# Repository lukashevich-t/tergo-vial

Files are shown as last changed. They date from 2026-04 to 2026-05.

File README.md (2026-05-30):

### Фичи:

- Раскладка Jiran (ну, почти...)
- Backlight
- Двойной shift работает как Enter
- Отображение состояния Caps/Num lock на экране
- отображение на экране текущего слоя клавы
- Отображение на экране активного на компе языка ввода (нужен агент на компе)
- Отображение активного на компе языка ввода в виде горящей/погасшей подсветки (нужен агент на компе)
- Активация режима Bootloader:
  - Если сбросить при нажатой кнопке 3 (только для левой половины)
  - Если на 3-м слое нажать 3 (на левой половине) или 8 (на правой)
  - Если сбросить при нажатой кнопке Boot на макетке (стандарт для RP2040)
  - "двойной клик" по сбросу
- На 3-м управляющем слое кнопка 5 (6) выдаёт на экран логотип и выплёвывает кой-какую информацию в debug console

### Структура папок

```
.
├── hardware                     # железная часть проекта
│   ├── case                     # Проекты корпусов
│   │   ├── tergo-choc           # Корпус для варианта tergo-choc
│   │   └── tergo-mx             # Корпус для варианта tergo-mx
│   ├── pcb                      # Проекты печатных плат
│   │   ├── 3rd-party-libs       # Сторонние библиотеки, откуда я взял символы и посадочные места для проектирования PCB
│   │   ├── common               #
│   │   │   └── libs             # Моя сборная библиотека символов и посадочных мест для KiCAD. Этот путь нужно прописать в Kicad в переменную TERGO_LIBS ("Preferences -> Configure paths")
│   │   ├── tergo-choc           # PCB для варианта tergo-choc
│   │   └── tergo-mx             # PCB для варианта tergo-mx
│   └── temp                     # Всякие временные тестовые файлы для прототипирования (KiCAD, FreeCAD...). Не для хранения в git
├── host-software                # ПО для ПК (взаимодействие ПК с клавиатурой)
│   ├── cinnamon-extension       # расширение для Cinnamon desktop для отображения текущей раскладки клавиатуры на экране клавиатуры
│   ├── cinnamon-extension-old   # предыдущая реализация (на javascript) расширения для Cinnamon desktop для отображения текущей раскладки клавиатуры на экране клавиатуры
│   └── windows-QmkLayoutMonitor # агент для Windows для отображения текущей раскладки клавиатуры на экране клавиатуры
├── layouts                      # Исходные коды прошивки для различных вариантов
│   ├── tergo-choc               # прошивка QMK-vial для варианта на low-profile свичах Kailh choc v1 (1350)
│   │   └── common.h             # Тут описаны отладочные макроопределения, которые могут печатать значения других макроопределений во время компиляции. Как использовать, см. ниже
│   └── tergo-mx                 # прошивка QMK-vial для варианта на свичах Cherry MX
│       └── common.h             # см. выше
└── logo                         # Битмап логотипа и шрифт, которым он напечатан. Скрипт для создания проявляющегося лого (см. инструкцию ниже)
    └── old_scripts              # старые скрипты для перегона битмапов в массив байтов для экрана. после отказа от драйвера OLED (перешел на Quantum painter) - потеряли актуальность.
/mnt/media/work/vial-qmk/keyboards/tergo/layouts/layout-tergo-mx/common.h
```

Пример использования отладочных макроопределений из файла `common.h`:

```c
#pragma message "RAW_USAGE_ID " DESCRIBE_MACRO_VALUE(RAW_USAGE_ID)
#pragma message DESCRIBE_MACRO(QMK_KEYBOARD_H)
```

### Preparation

- TBD...
- After cloning git repository, go to Kicad path variables and define variable `TERGO_LIBS` to point to <repo>/pcb/common/libs, i.e.: `TERGO_LIBS => /home/tim/work/qmk_firmware/keyboards/tergo/pcb/common/libs`

### Печать корпуса

- Примечание: иногда при экспорте файлов STL из проекта freecad они получаются битые - слайсер ругается на них. В этом случае попробовать отключить/включить активность импортируемого тела, поворочать, экспортировать снова... Короче, поплясать с бубном.
- Из проекта Freecad (`./case/case-left.FCStd`) экспортировать в формат STL тело "full-top-new" - это верх левой половины.
- Верх правой половины получить средствами слайсера (отзеркалить).
- Напечатать.
- Эспортировать тела "full-bottom-new-left-with-logo" и "full-bottom-new-left-with-logo".
- Напечатать.

### Отображение раскладки клавиатуры

- скомпилить поддержку HID RAW (`RAW_ENABLE = yes` и обработчик сообщений).
- прошить в клаву
- для Linux Mint cinnamon edition использовать проект `_cinnamon-extension` или `_cinnamon-extension-old`
- Для Windows собрать `_windows-QmkLayoutMonitor` в соответствии с инструкцией в папке

### Логотип

- Подготовить файл `logo/logo.png` с разрешением 320x1280 пикселей (вертикальная ориентация). Лучше всего будет смотреться белые буквы на черном фоне.
- В скрипте `logo/create-logo-animation.py` подобрать под себя количество и длительность кадров анимации.
- Если логотип скорее черный на белом, придётся подправить скрипт:
  - `if img_1bit.getpixel((x, y)) > 0:` заменить на `if img_1bit.getpixel((x, y)) == 0:`
  - `current_frame.putpixel(px, 255)` заменить на `current_frame.putpixel(px, 0)`
- запустить питонский скрипт:

```bash
cd logo
python3 create-logo-animation.py
```

- появится папка с отдельными кадрами, а также анимированный файл `logo.gif`
- натравить на него преобразователь картинок:

```bash
rm -rf converted-image && mkdir -p converted-image && qmk painter-convert-graphics -f mono2 -o ./converted-image -i logo.gif
```

- содержимое папки `logo/converted-image/logo.qgf.*` переписать в `split/display/` с заменой файлов.
- Пересобрать прошивку.

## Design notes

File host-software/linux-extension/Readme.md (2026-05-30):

## tergo-layout@tlukashevich.com
Расширения для Cinnamon desktop и Gnome desktop для отправки сообщений о смене раскладки в клавиатуру T-Ergo на основе прошивки QMK-vial  

### Установка
- при желании можно заново скомпилировать программу для общения с клавиатурой:
```bash
apt install libhidapi-dev gcc -y 
gcc send_hid.c -o send_hid -lhidapi-hidraw -s
```
- В файлах `cinnamon.yaml` и `gnome.yaml` в секции переменных указать "координаты" клавиатуры: vid (5954), pid(0003) и hid_raw_usage_page (FF60 по умолчанию для клавиатур на QMK)
- запустить установку для нужного десктопа:
```bash
ansible-playbook cinnamon.yaml -K
# или ansible-playbook gnome.yaml -K
```
- перезапустить рабочий стол (просто выйти и зайти не сработает):
```bash
systemctl restart display-manager # для gnome
systemctl restart lightdm # для cinnamon
```

### Полезные команды
#### Gnome
```bash
# отключить расширение:
gnome-extensions disable tergo-layout@tlukashevich.com
# Перезагрузить расширение. Всё равно не работает, и надо при изменениях перестартовать display-manager:
gnome-extensions reset tergo-layout@tlukashevich.com
# включить расширение
gnome-extensions enable tergo-layout@tlukashevich.com
# список включённых расширений
gsettings get org.gnome.shell enabled-extensions
# список всех расширений
gnome-extensions list
```

Наблюдать за логами:
```bash
journalctl -f -g 'tergo'
```

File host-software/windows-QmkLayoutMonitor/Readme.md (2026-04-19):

## QML Layout monitor
Агент для Windows, отслеживающий изменения раскладки и передающий эту информацию в T-Ergo keyboard
### Установка
- при желании можно заново скомпилировать.
  - Потребуется MS Visual Studio 2022 с включенной опцией "Windows C++ development"
  - Запустить Developer Command Prompt for Visual Studio 2022
  - перейти в папку с проектом и собрать:
```cmd
cd e:\temp\QMKLayoutMonitor\QMKLayoutMonitor
cl /EHsc *.cpp /Fe:QMKLayoutMonitor.exe /link /SUBSYSTEM:WINDOWS
# или с оптимизацией:
cl /EHsc /O1 /MD *.cpp /Fe:QMKLayoutMonitor.exe /link /SUBSYSTEM:WINDOWS
```
- для установки запустить так:
```cmd
QmkLayoutMonitor.exe <VID> <PID> <USAGE_PAGE> install
```
Программа скопирует себя в %APPDATA% (c:/Users/tim/AppData/Roaming/QMKLayoutMonitor/QMKLayoutMonitor.exe) и создаст ярлык в автозапуске (`shell:startup`) с указанными параметрами VID, PID и USAGE_PAGE.

### Прочие заметки
- Чтобы писать отладочные сообщения в файл `layout_monitor.log` в папке с программой, надо прописать в коде `#define DEBUG` и перекомпилировать.
- просто запустить:
```cmd
QmkLayoutMonitor.exe <VID> <PID> <USAGE_PAGE>
# Пример:
QmkLayoutMonitor.exe 0x5954 0x0003 0xFF60
```
- Проверить связи с клавиатурой:
```cmd
QmkLayoutMonitor.exe 0x5954 0x0003 0xff60 test
```
программа просто отправит в клавиатуру текущую раскладку и завершится.
- Программе не всегда приходят уведомления о смене раскладки. Например, при смене раскладки с EN на RU через иконку в system tray. При смене раскладки в обратную сторону через system tray - обновления приходят.
- С помощью ИИ перепробовал кучу вариантов:
  - Через Text Services Framework - но оказалось, что тут уведомления приходят только о смене раскладки для нашего приложения, а не для глобально
  - Через периодический опрос - это мне не нравится, хотя так сделано в клавиатуре stront ([вот](https://github.com/zzeneg/qmk-hid-host) проект на Rust)
  - Через перехват WM_SHELL - это по словам ИИ не работает начиная с Windows 8
  - Комбинированный метод, который у нас тут и используется: отслеживаем изменение активного окна плюс отпускание кнопок, которые применяются в переключении языков (Ctrl, Shift, Alt, Win...). Это работает почти хорошо.

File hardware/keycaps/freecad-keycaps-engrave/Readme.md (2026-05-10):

# Назначение
Макрос FreeCAD для нанесения гравировки на кейкапы [KLP-Lame](https://github.com/braindefender/KLP-Lame-Keycaps)  
Испытывался на кейкапах "Choc stem - choc size" в FreeCAD v1.1.1  

# Установка
проще всего создать симлинки:
```bash
cd $HOME/.local/share/FreeCAD/v1-1/Macro
ln -s /path_to_repo/freecad-keycaps-engrave/keycap_engrave.FCMacro
ln -s /path_to_repo/freecad-keycaps-engrave/keycap_engrave_libs
```

Но можно и просто скопировать файл `keycap_engrave.FCMacro` и папку `keycap_engrave_libs` в `$HOME/.local/share/FreeCAD/v1-1/Macro/`  

# Разработка
Для настройки удобств при разработке макросов для FreeCAD в VS Code + Pylance придётся сделать кучу шагов:
- Freecad поставляется в формате AppImage, а это по сути образ squashfs. Настроим, чтобы он всегда монтировался:
```bash
sudo mkdir /mnt/freecad
# Узнаем, с какого смещения в файле Appimage начинается собственно образ:
OFFSET=`/opt/AppImages/FreeCAD_1.1.1-Linux-x86_64-py311.AppImage --appimage-offset`
echo "/opt/AppImages/FreeCAD_1.1.1-Linux-x86_64-py311.AppImage /mnt/freecad   squashfs        loop,offset=$OFFSET      0 0" | sudo tee -a /etc/fstab
```

- установить freecad-stubs:
	a. из гитхаба:
	```bash
	mkdir -p /home/tim/work/freecad && cd $_
	git clone https://github.com/ostr00000/freecad-stubs.git
	```
	b. в виртуальное окружение
	```bash
	mkdir -p /home/tim/work/freecad && cd $_
	python3 -m venv freecad-venv
	source freecad-venv/bin/activate
	pip3 install freecad-stubs
	```
- в проекте создать файл `.vscode/settings.json`:
```json
{
	"files.associations": {
	    "*.FCMacro": "python" // чтобы VSCode считал файлы *.FCMacro кодом на Python
	},
    "python.analysis.extraPaths": [
      "./libs", // просто наша либа в рамках проекта
      "/mnt/freecad/usr/bin", // пути к папкам с so-файлами Freecad
      "/mnt/freecad/usr/lib"
    ],
	"python.analysis.stubPath": "/home/tim/work/freecad/freecad-stubs/freecad_stubs", // путь к стабам (биндингам)
	"python.analysis.typeCheckingMode": "standard",
}
```

# Проблемы
Иногда случаются проблемы при нанесении гравировки. Помогает открыть проблемный кейкап в FreeCAD и поднять выдавленный 3Д-текст на 1 мкм по оси Z.

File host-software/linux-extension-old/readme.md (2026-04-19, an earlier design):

## cinnamon-to-tergo
Расширение для Cinnamon desktop для отправки сообщений о смене раскладки в клавиатуру T-Ergo на основе прошивки QMK  
## Установка
- установка необходимых библиотек
```bash
sudo apt install libhidapi-hidraw0
```
- Установка nodejs
```bash
apt install nodejs
cd /path/to/git/repo/_cinnamon-extension/cinnamon-to-tergo@tlukashevich.com
npm install

# Скопировать проект в папку расширений cinnamon:
cp -r /path/to/git/repo/_cinnamon-extension/cinnamon-to-tergo@tlukashevich.com ~/.local/share/cinnamon/extensions/
# или сделать ссылку:
ln -s /path/to/git/repo/_cinnamon-extension/cinnamon-to-tergo@tlukashevich.com ~/.local/share/cinnamon/extensions/cinnamon-to-tergo@tlukashevich.com
```
- настройка udev - дать доступ к устройству обычному пользователю. Проверить правильность Vendor ID/Product ID:
```bash
echo -e 'SUBSYSTEM=="hidraw", ATTRS{idVendor}=="5954", ATTRS{idProduct}=="0003", MODE="0666"\nSUBSYSTEM=="usb", ATTRS{idVendor}=="5954", ATTRS{idProduct}=="0003", MODE="0666"' | sudo tee /etc/udev/rules.d/99-qmk-raw-hid.rules
sudo udevadm control --reload-rules
sudo udevadm trigger
```
- **Переподключить клавиатуру!!!**
- Запустить отладчик Looking glass из состава Cinnamon (запустить команду `lg` или назначить и нажать горячую кнопку)
- Активировать расширение: Запустить "Параметры -> Расширения". Там должно быть наше расширение. Выделить его и нажать плюс внизу окна
- При активации Cinnamon может упасть, но потом всё работает
- Перезапустить Cinnamon. Это можно сделать без выхода:
  - из Looking glass -> Actions
  - Нажать Alt+F2 (или Win+R) и запустить команду `r` (да, одна буква)
- Логи можно смотреть в том же Looking glass

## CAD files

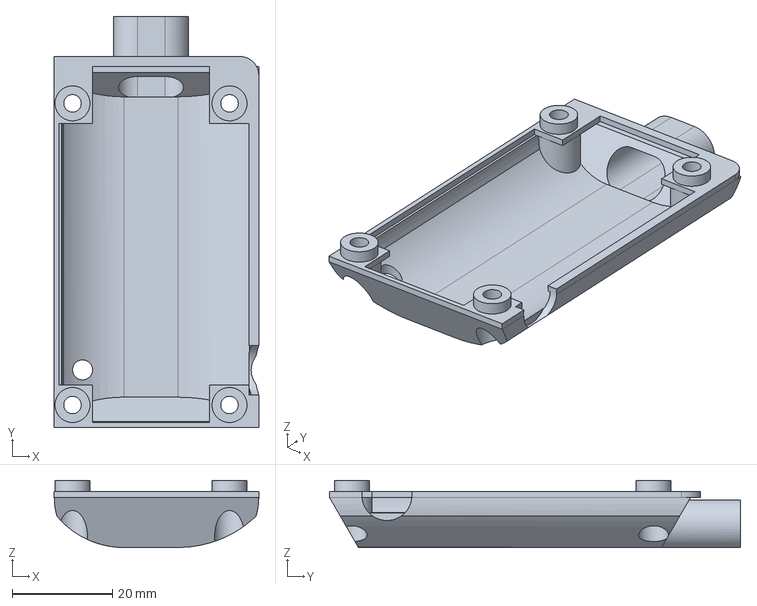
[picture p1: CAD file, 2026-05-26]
hardware/case/tergo_choc/case-choc.FCStd
40.9 x 82.2 x 13.4 mm

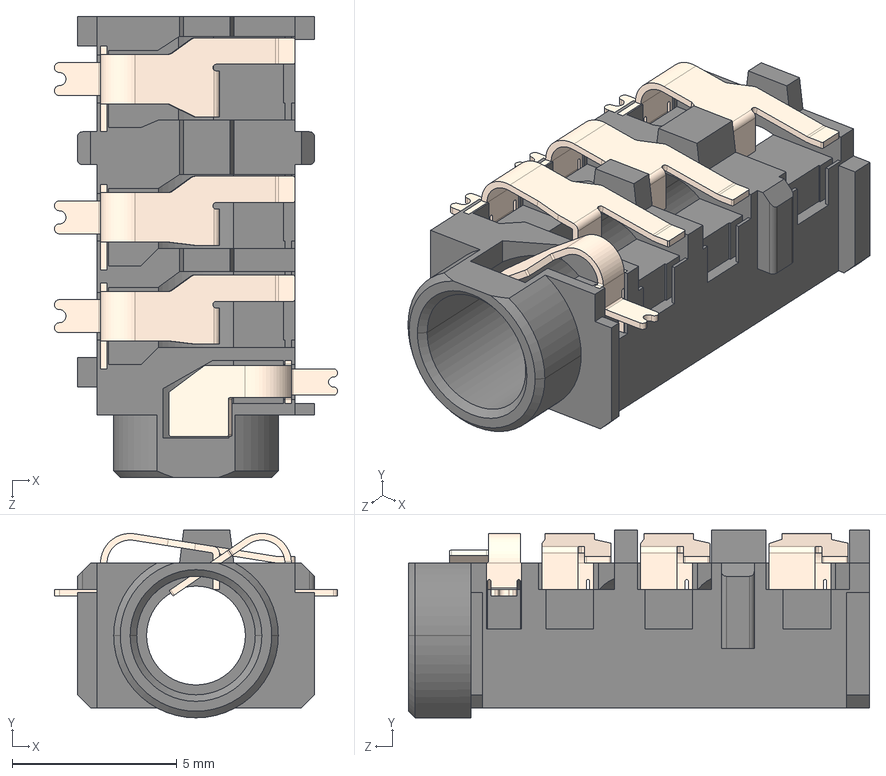
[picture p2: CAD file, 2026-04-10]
hardware/pcb/3rd-party-libs/keebio-parts/3dmodels/CUI_SJ-43614-SMT-TR.step
8.60 x 5.70 x 14.0 mm

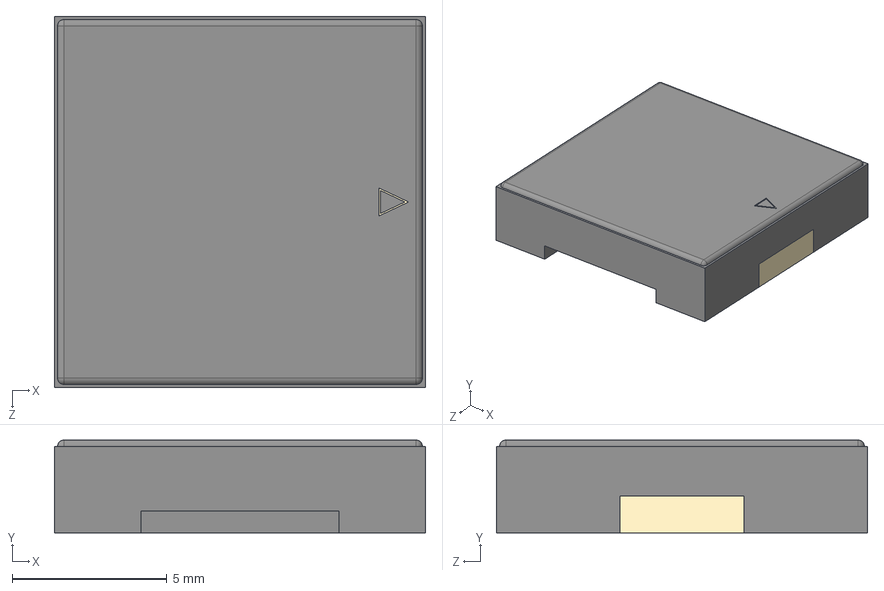
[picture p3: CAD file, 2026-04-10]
hardware/pcb/3rd-party-libs/speaker/PKLCS1212E4001-R1.step
12.0 x 3.00 x 12.0 mm

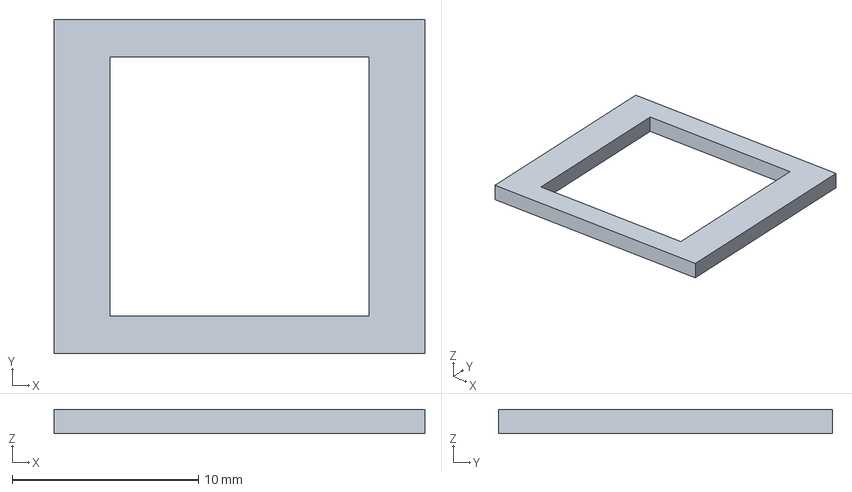
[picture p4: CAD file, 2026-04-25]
hardware/temp/choc-plate.FCStd
19.9 x 17.9 x 1.30 mm

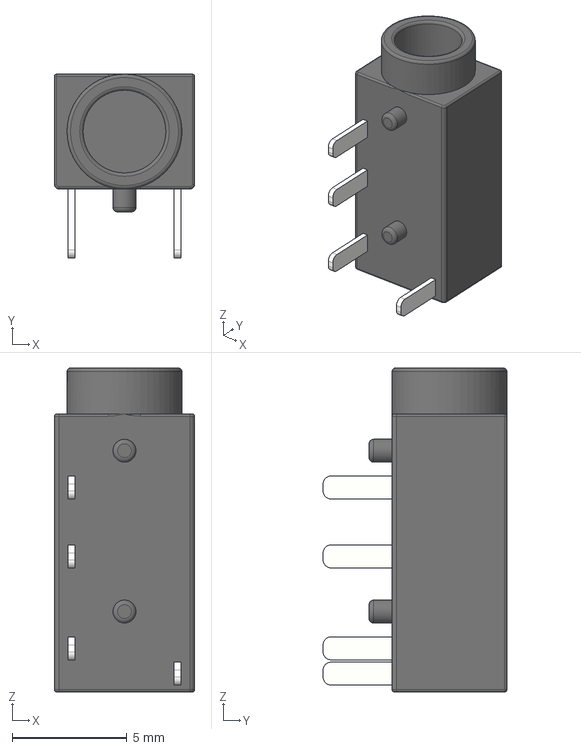
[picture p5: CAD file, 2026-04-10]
hardware/pcb/3rd-party-libs/keebio-parts/3dmodels/PJ-320A.step
6.10 x 8.00 x 14.1 mm

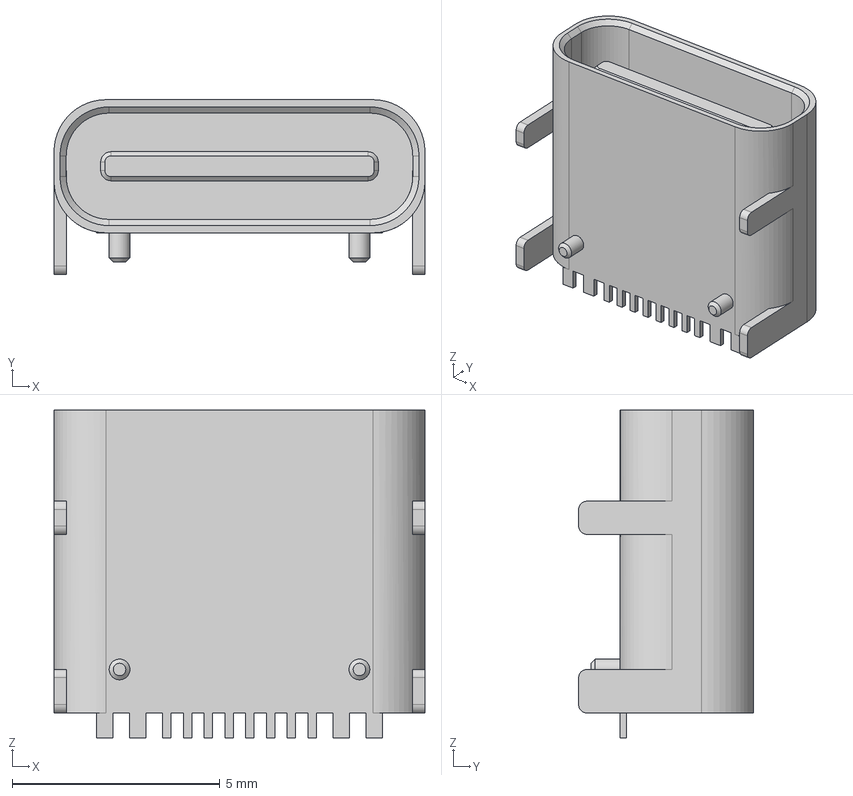
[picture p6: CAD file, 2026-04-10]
hardware/pcb/3rd-party-libs/keebio-parts/3dmodels/HRO TYPE-C-31-M-12.step
8.94 x 4.21 x 7.90 mm

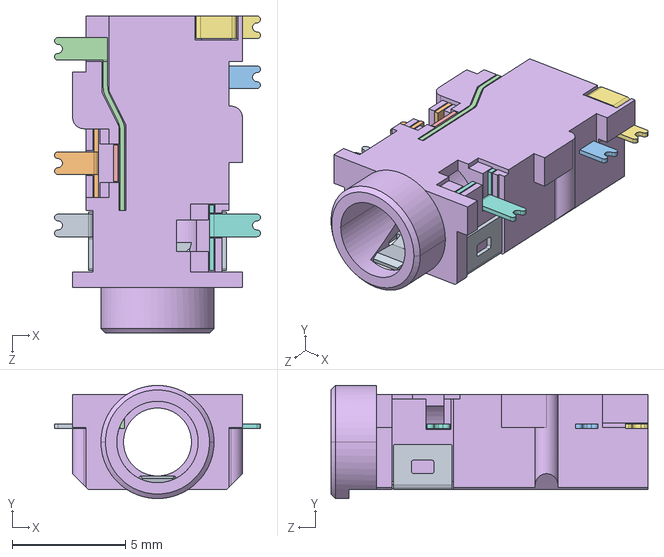
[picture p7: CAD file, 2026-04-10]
hardware/pcb/3rd-party-libs/keebio-parts/3dmodels/CUI_DEVICES_SJ-43504-SMT-TR.step
9.10 x 5.00 x 14.0 mm

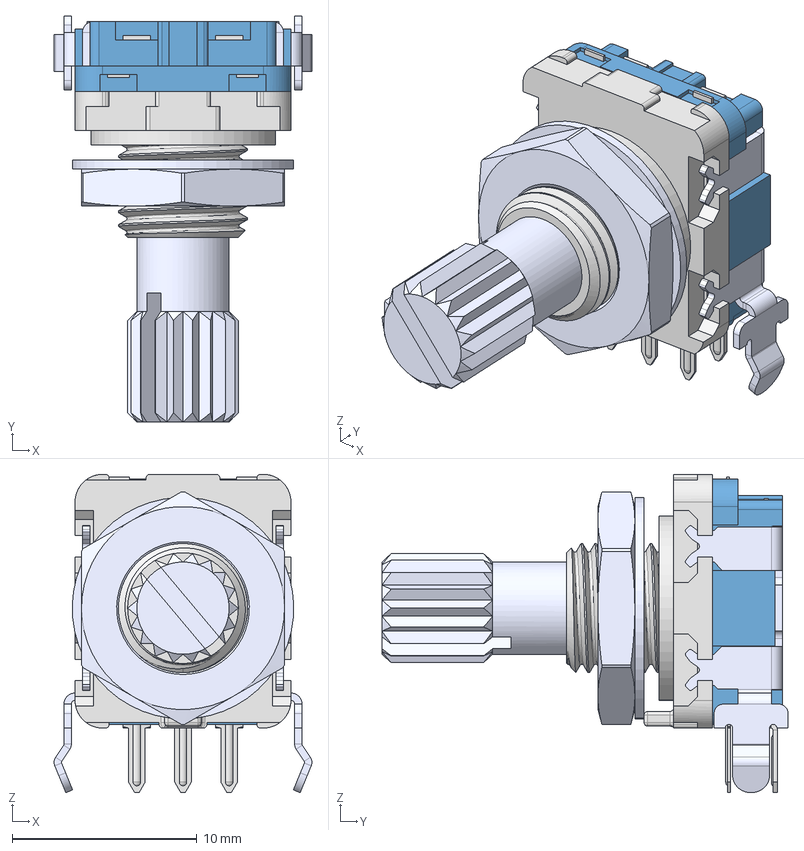
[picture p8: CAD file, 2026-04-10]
hardware/pcb/3rd-party-libs/keebio-parts/3dmodels/EC11B-SW-Horiz-15K-blue.step
14.0 x 22.0 x 17.3 mm

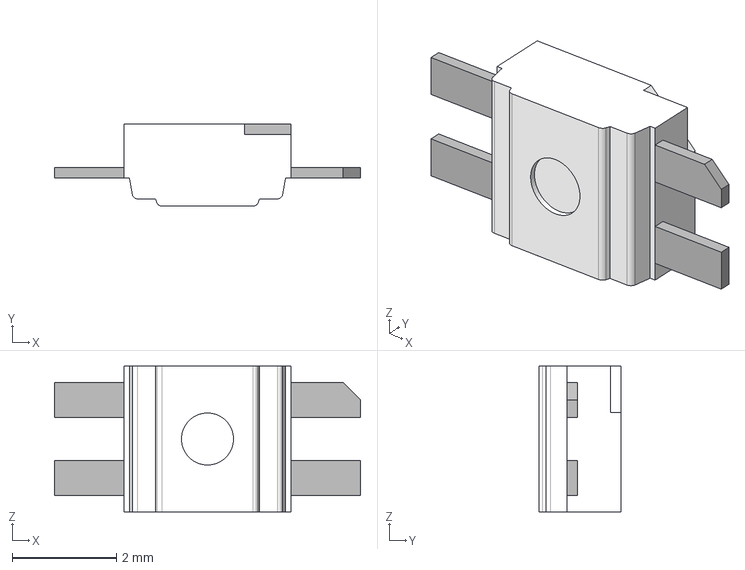
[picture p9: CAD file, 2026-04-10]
hardware/pcb/3rd-party-libs/keebio-parts/3dmodels/SK6812MINI-E v1.step
5.88 x 1.58 x 2.80 mm

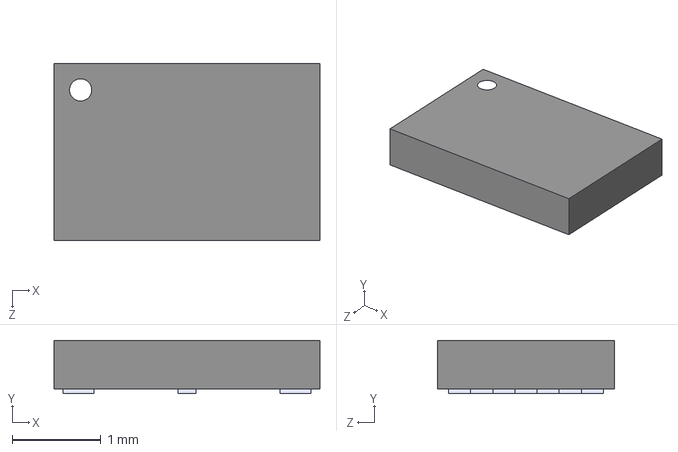
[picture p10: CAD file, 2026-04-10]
hardware/pcb/3rd-party-libs/keebio-parts/3dmodels/W25Q16JVUXIQ.step
3.00 x 0.6 x 2.00 mm

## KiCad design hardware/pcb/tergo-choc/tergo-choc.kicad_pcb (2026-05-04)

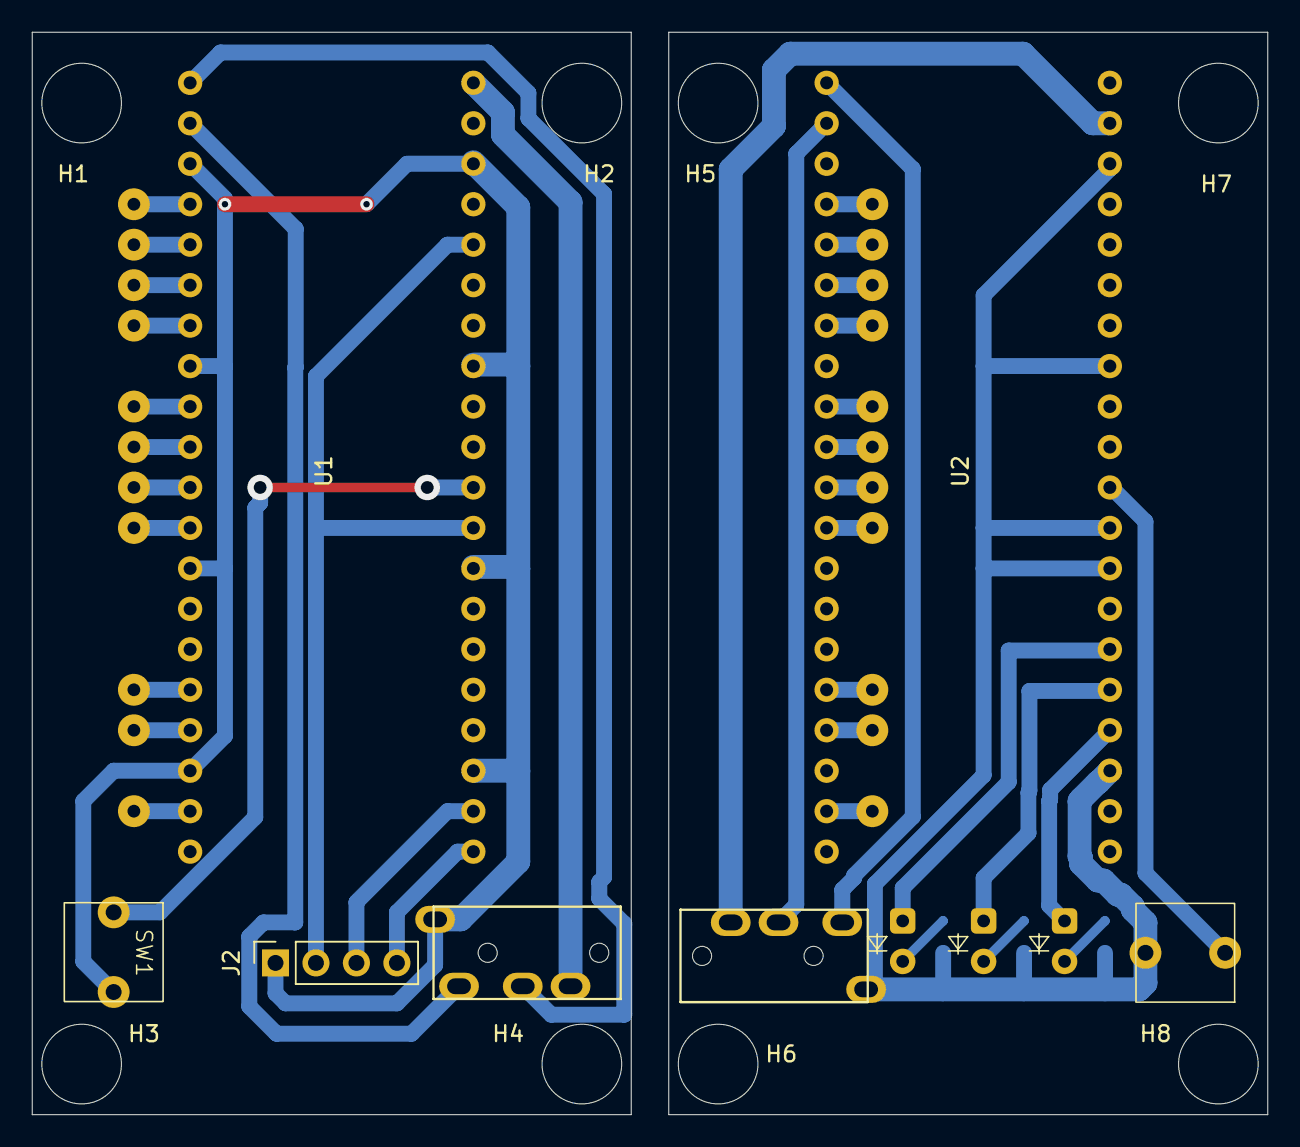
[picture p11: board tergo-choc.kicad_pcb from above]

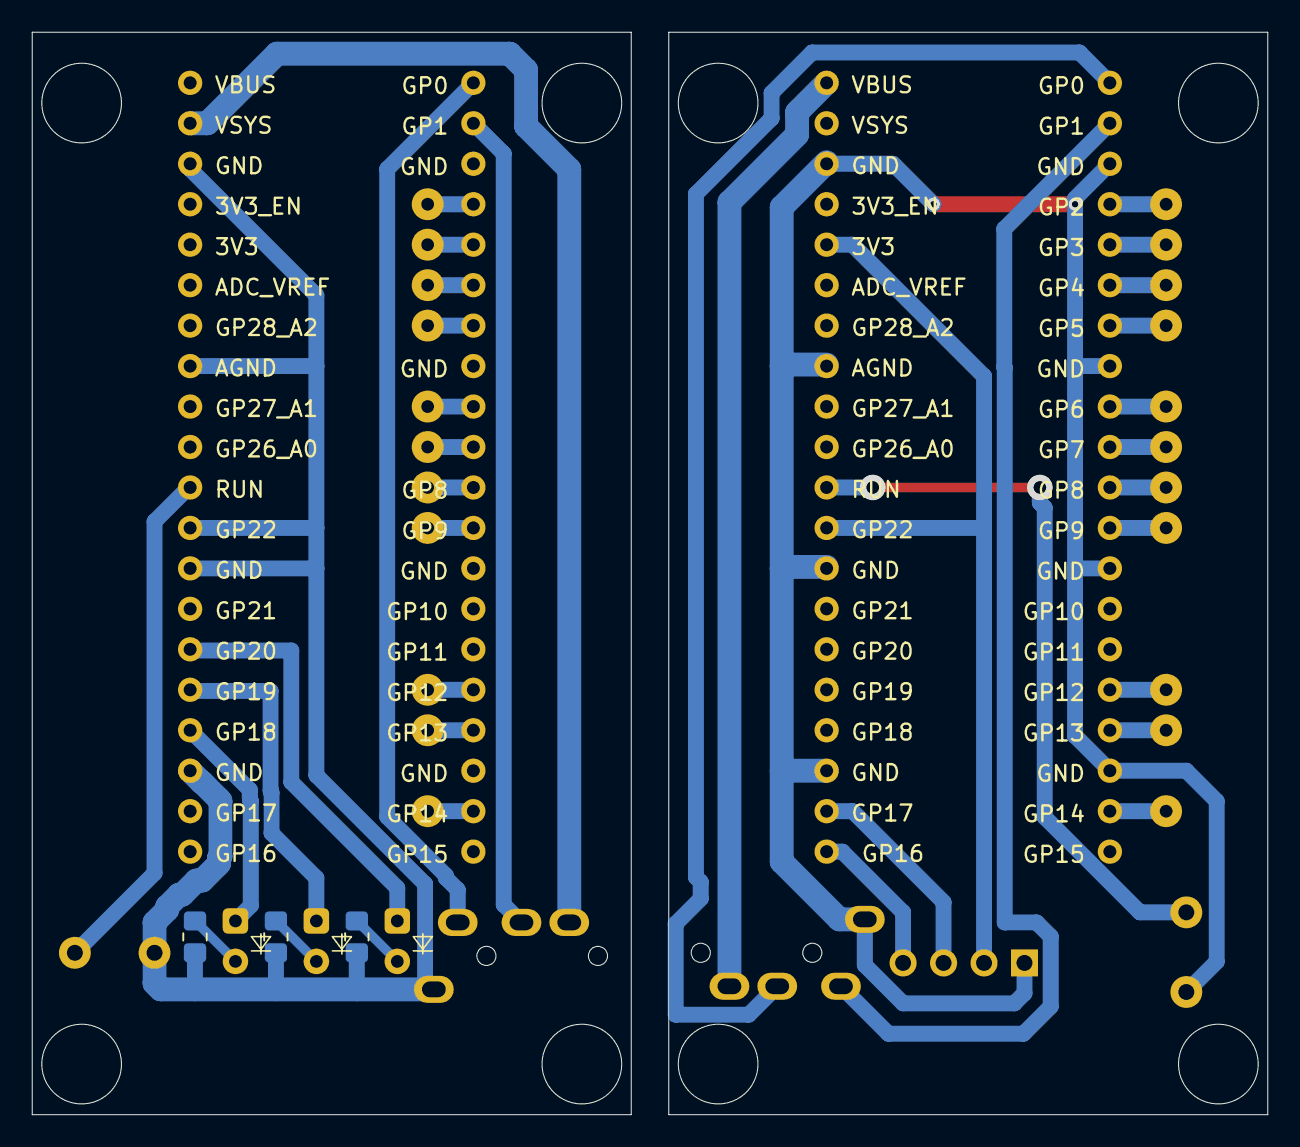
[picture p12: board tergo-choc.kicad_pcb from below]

Board: 2 copper layers, 77.6 x 67.9 mm, 43 parts (3 on the bottom side), 40 nets.

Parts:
D10: NL; LED_1.8mm
D59: CL; LED_1.8mm
D60: SL; LED_1.8mm
H1, H2, H3, H4, H5, H6, H7, H8: MountingHole; MountHole_5mm
J1, J3: TRRS_SOCKET; MJ-4PP-9
J2: Conn_01x04_Socket; PinSocket_1x04_P2.54mm_Vertical
J12, J13, J14, J15, J18, J19, J20, J21, J22, J23, J24, J25, J26, J27, J28, J29, J30, J31, J32, J33, J34, J35: Conn_01x01_Socket; THT_PAD
R1, R3, R4: R_Small; R_0805_2012Metric_Pad1.20x1.40mm_HandSolder
SW1: RST_LEFT; pushbutton-THT-2pin
SW30: RST_RIGHT; pushbutton-THT-2pin
U1, U2: Raspberry_Pi_Pico

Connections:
/3V3_L: J2.2, U1.29 (GP22), U1.36 (3V3)
/CAPS_LOCK: D59.2 (A), U2.25 (GP19)
/COL0_L: J12.1 (Pin_1_1), U1.4 (GP2)
/COL0_R: J25.1 (Pin_1_1), U2.4 (GP2)
/COL1_L: J15.1 (Pin_1_1), U1.7 (GP5)
/COL1_R: J28.1 (Pin_1_1), U2.7 (GP5)
/COL2_L: J14.1 (Pin_1_1), U1.6 (GP4)
/COL2_R: J27.1 (Pin_1_1), U2.6 (GP4)
/COL3_L: J19.1 (Pin_1_1), U1.10 (GP7)
/COL3_R: J30.1 (Pin_1_1), U2.10 (GP7)
/COL4_L: J20.1 (Pin_1_1), U1.11 (GP8)
/COL4_R: J31.1 (Pin_1_1), U2.11 (GP8)
/COL5_L: J21.1 (Pin_1_1), U1.12 (GP9)
/COL5_R: J32.1 (Pin_1_1), U2.12 (GP9)
/DISPLAY_SCL: J2.3, U1.22 (GP17/SCL)
/DISPLAY_SDA: J2.4, U1.21 (GP16/SDA)
/NUM_LOCK: D10.2 (A), U2.26 (GP20)
/ROWA_L: J13.1 (Pin_1_1), U1.5 (GP3)
/ROWA_R: J26.1 (Pin_1_1), U2.5 (GP3)
/ROWB_L: J18.1 (Pin_1_1), U1.9 (GP6)
/ROWB_R: J29.1 (Pin_1_1), U2.9 (GP6)
/ROWC_L: J22.1 (Pin_1_1), U1.16 (GP12)
/ROWC_R: J33.1 (Pin_1_1), U2.16 (GP12)
/ROWD_L: J23.1 (Pin_1_1), U1.17 (GP13)
/ROWD_R: J34.1 (Pin_1_1), U2.17 (GP13)
/ROWE_L: J24.1 (Pin_1_1), U1.19 (GP14)
/ROWE_R: J35.1 (Pin_1_1), U2.19 (GP14)
/RST_L: SW1.1 (C), U1.30 (RUN)
/RST_R: SW30.1 (C), U2.30 (RUN)
/RX_L: J1.D, U1.2 (GP1/RX)
/RX_R: J3.C, U2.2 (GP1/RX)
/SCROLL_LOCK: D60.2 (A), U2.24 (GP18)
/TX_L: J1.C, U1.1 (GP0/TX)
/TX_R: J3.D, U2.1 (GP0/TX)
/VIN_R: J3.B, U2.39 (Vin)
/VOUT_L: J1.B, U1.40 (Vout)
GND: J1.A, J2.1, J3.A, R1.2, R3.2, R4.2, SW1.2 (D), SW30.2 (D), U1.3 (GND), U1.8 (GND), U1.13 (GND), U1.18 (GND), U1.23 (GND), U1.28 (GND), U1.33 (AGND), U1.38 (GND), U2.23 (GND), U2.28 (GND), U2.29 (GP22), U2.33 (AGND), U2.38 (GND)
unnamed: D10.1 (K), R1.1
unnamed: D59.1 (K), R3.1
unnamed: D60.1 (K), R4.1

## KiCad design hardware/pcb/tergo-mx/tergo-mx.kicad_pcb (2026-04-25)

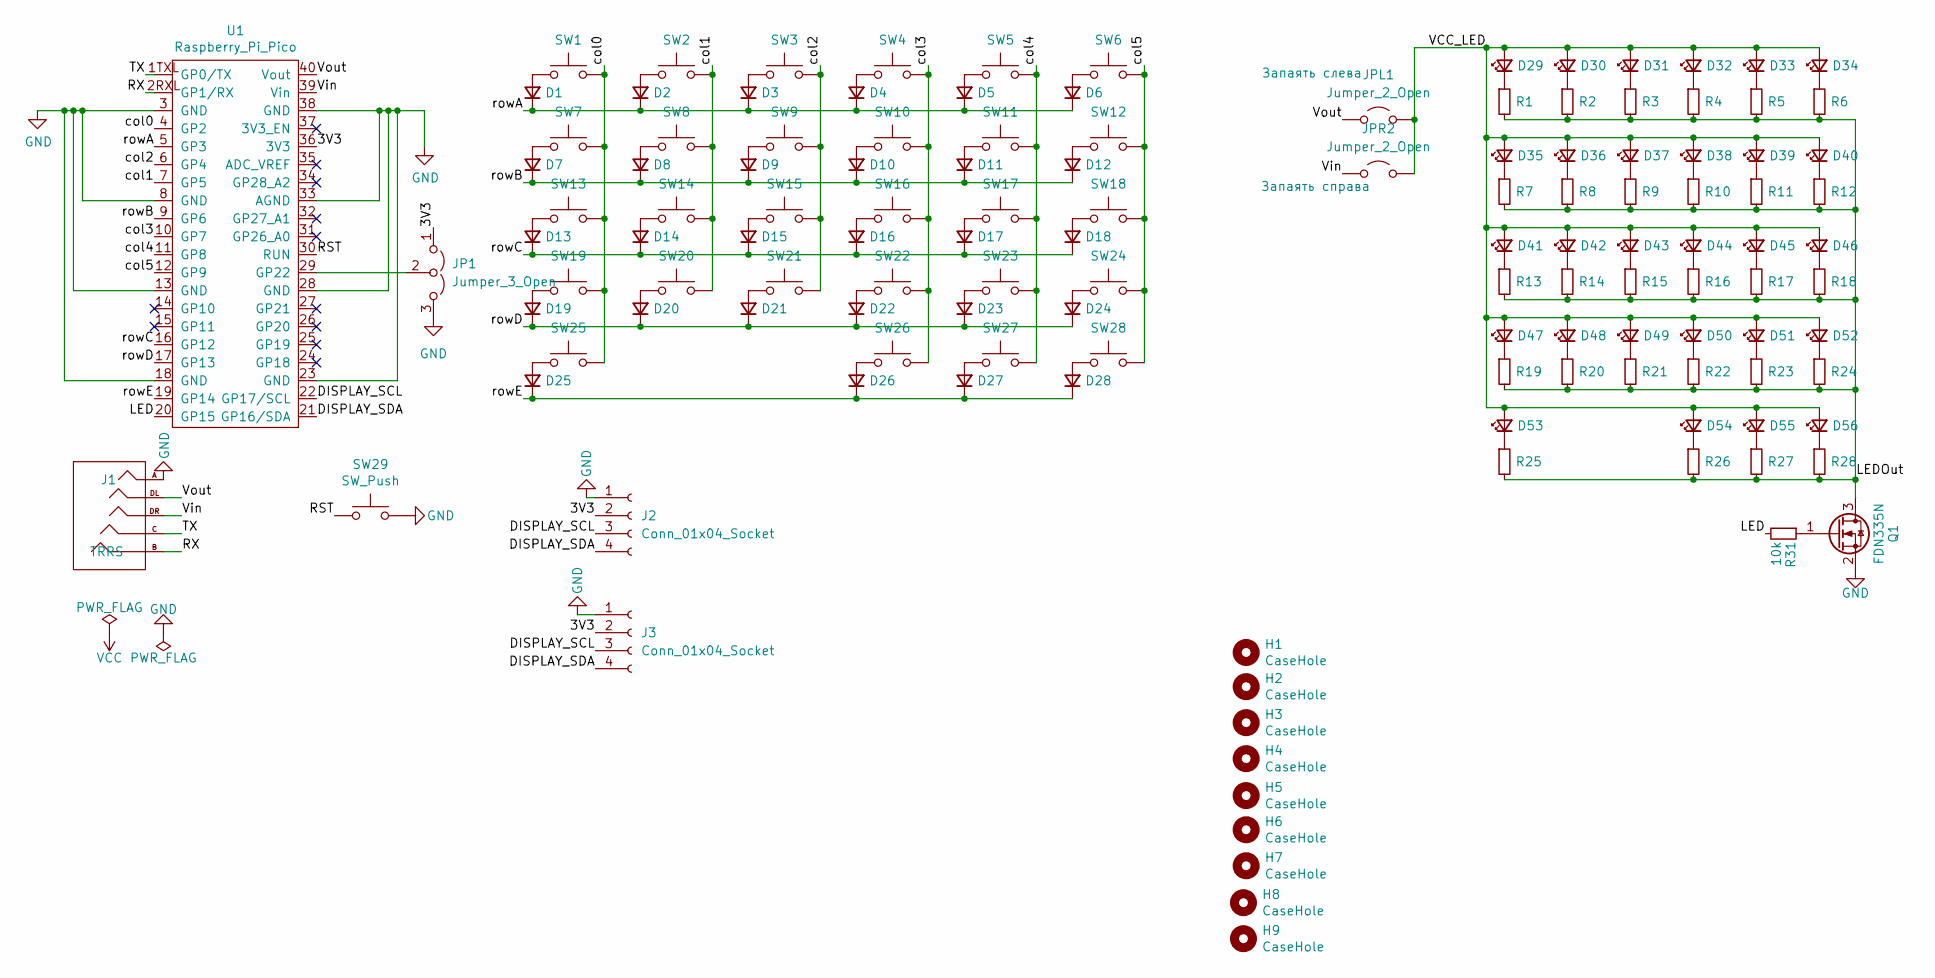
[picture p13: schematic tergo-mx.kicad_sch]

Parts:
D1, D2, D3, D4, D5, D6, D7, D8, D9, D10, D11, D12, D13, D14, D15, D16, D17, D18, D19, D20, D21, D22, D23, D24, D25, D26, D27, D28: D_Small; Diode-Hybrid-2sided
D29, D30, D31, D32, D33, D34, D35, D36, D37, D38, D39, D40, D41, D42, D43, D44, D45, D46, D47, D48, D49, D50, D51, D52, D53, D54, D55, D56: LED_Small; LED_1.8mm
H1, H2, H3, H4, H5, H6, H7, H8, H9: CaseHole; MountHole
J1: TRRS; MJ-4PP-9-mirrored
J2, J3: Conn_01x04_Socket; PinHeader_1x04_P2.54mm_Vertical
JP1: Jumper_3_Open; SolderJumper-3_P1.3mm_Open_RoundedPad1.0x1.5mm
JPL1: Jumper_2_Open; SolderJumper-2_P1.3mm_Open_RoundedPad1.0x1.5mm
JPR2: Jumper_2_Open; SolderJumper-2_P1.3mm_Open_RoundedPad1.0x1.5mm
Q1: FDN335N; SOT-23
R1, R2, R3, R4, R5, R6, R7, R8, R9, R10, R11, R12, R13, R14, R15, R16, R17, R18, R19, R20, R21, R22, R23, R24, R25, R26, R27, R28: R_Small; Resistor-Hybrid-2sided
R31: 10k; Resistor-Hybrid-2sided
SW1, SW2, SW3, SW4, SW5, SW6, SW7, SW8, SW9, SW10, SW11, SW12, SW13, SW14, SW15, SW16, SW17, SW18, SW19, SW20, SW21, SW22, SW23, SW24, SW25, SW26, SW27, SW28: SW_Push; SW_Hotswap_Kailh_MX_Plated_mirrored2_1.00u
SW29: SW_Push; ResetSW
U1: Raspberry_Pi_Pico; Raspberry_Pi_Pico_dual

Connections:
/3V3: J2.2, J3.2, JP1.1 (A), U1.36 (3V3)
/DISPLAY_SCL: J2.3, J3.3, U1.22 (GP17/SCL)
/DISPLAY_SDA: J2.4, J3.4, U1.21 (GP16/SDA)
/LED: R31.2, U1.20 (GP15)
/LEDOut: Q1.3 (D), R1.2, R2.2, R3.2, R4.2, R5.2, R6.2, R7.2, R8.2, R9.2, R10.2, R11.2, R12.2, R13.2, R14.2, R15.2, R16.2, R17.2, R18.2, R19.2, R20.2, R21.2, R22.2, R23.2, R24.2, R25.2, R26.2, R27.2, R28.2
/RST: SW29.1, U1.30 (RUN)
/RX: J1.B, U1.2RXL (GP1/RX)
/TX: J1.C, U1.1TXL (GP0/TX)
/VCC_LED: D29.2 (A), D30.2 (A), D31.2 (A), D32.2 (A), D33.2 (A), D34.2 (A), D35.2 (A), D36.2 (A), D37.2 (A), D38.2 (A), D39.2 (A), D40.2 (A), D41.2 (A), D42.2 (A), D43.2 (A), D44.2 (A), D45.2 (A), D46.2 (A), D47.2 (A), D48.2 (A), D49.2 (A), D50.2 (A), D51.2 (A), D52.2 (A), D53.2 (A), D54.2 (A), D55.2 (A), D56.2 (A), JPL1.2 (B), JPR2.2 (B)
/Vin: J1.DR, JPR2.1 (A), U1.39 (Vin)
/Vout: J1.DL, JPL1.1 (A), U1.40 (Vout)
/col0: SW1.2, SW7.2, SW13.2, SW19.2, SW25.2, U1.4 (GP2)
/col1: SW2.2, SW8.2, SW14.2, SW20.2, U1.7 (GP5)
/col2: SW3.2, SW9.2, SW15.2, SW21.2, U1.6 (GP4)
/col3: SW4.2, SW10.2, SW16.2, SW22.2, SW26.2, U1.10 (GP7)
/col4: SW5.2, SW11.2, SW17.2, SW23.2, SW27.2, U1.11 (GP8)
/col5: SW6.2, SW12.2, SW18.2, SW24.2, SW28.2, U1.12 (GP9)
/rowA: D1.1 (K), D2.1 (K), D3.1 (K), D4.1 (K), D5.1 (K), D6.1 (K), U1.5 (GP3)
/rowB: D7.1 (K), D8.1 (K), D9.1 (K), D10.1 (K), D11.1 (K), D12.1 (K), U1.9 (GP6)
/rowC: D13.1 (K), D14.1 (K), D15.1 (K), D16.1 (K), D17.1 (K), D18.1 (K), U1.16 (GP12)
/rowD: D19.1 (K), D20.1 (K), D21.1 (K), D22.1 (K), D23.1 (K), D24.1 (K), U1.17 (GP13)
/rowE: D25.1 (K), D26.1 (K), D27.1 (K), D28.1 (K), U1.19 (GP14)
GND: J1.A, J2.1, J3.1, JP1.3 (B), Q1.2 (S), SW29.2, U1.3 (GND), U1.8 (GND), U1.13 (GND), U1.18 (GND), U1.23 (GND), U1.28 (GND), U1.33 (AGND), U1.38 (GND)
unnamed: D1.2 (A), SW1.1
unnamed: D2.2 (A), SW2.1
unnamed: D3.2 (A), SW3.1
unnamed: D4.2 (A), SW4.1
unnamed: D5.2 (A), SW5.1
unnamed: D6.2 (A), SW6.1
unnamed: D7.2 (A), SW7.1
unnamed: D8.2 (A), SW8.1
unnamed: D9.2 (A), SW9.1
unnamed: D10.2 (A), SW10.1
unnamed: D11.2 (A), SW11.1
unnamed: D12.2 (A), SW12.1
unnamed: D13.2 (A), SW13.1
unnamed: D14.2 (A), SW14.1
unnamed: D15.2 (A), SW15.1
unnamed: D16.2 (A), SW16.1
unnamed: D17.2 (A), SW17.1
unnamed: D18.2 (A), SW18.1
unnamed: D19.2 (A), SW19.1
unnamed: D20.2 (A), SW20.1
unnamed: D21.2 (A), SW21.1
unnamed: D22.2 (A), SW22.1
unnamed: D23.2 (A), SW23.1
unnamed: D24.2 (A), SW24.1
unnamed: D25.2 (A), SW25.1
unnamed: D26.2 (A), SW26.1
unnamed: D27.2 (A), SW27.1
unnamed: D28.2 (A), SW28.1
unnamed: D29.1 (K), R1.1
unnamed: D30.1 (K), R2.1
unnamed: D31.1 (K), R3.1
unnamed: D32.1 (K), R4.1
unnamed: D33.1 (K), R5.1
unnamed: D34.1 (K), R6.1
unnamed: D35.1 (K), R7.1
unnamed: D36.1 (K), R8.1
unnamed: D37.1 (K), R9.1
unnamed: D38.1 (K), R10.1
unnamed: D39.1 (K), R11.1
unnamed: D40.1 (K), R12.1
unnamed: D41.1 (K), R13.1
unnamed: D42.1 (K), R14.1
unnamed: D43.1 (K), R15.1
unnamed: D44.1 (K), R16.1
unnamed: D45.1 (K), R17.1
unnamed: D46.1 (K), R18.1
unnamed: D47.1 (K), R19.1
unnamed: D48.1 (K), R20.1
unnamed: D49.1 (K), R21.1
unnamed: D50.1 (K), R22.1
unnamed: D51.1 (K), R23.1
unnamed: D52.1 (K), R24.1
unnamed: D53.1 (K), R25.1
unnamed: D54.1 (K), R26.1
unnamed: D55.1 (K), R27.1
unnamed: D56.1 (K), R28.1
unnamed: JP1.2 (C), U1.29 (GP22)
unnamed: Q1.1 (G), R31.1

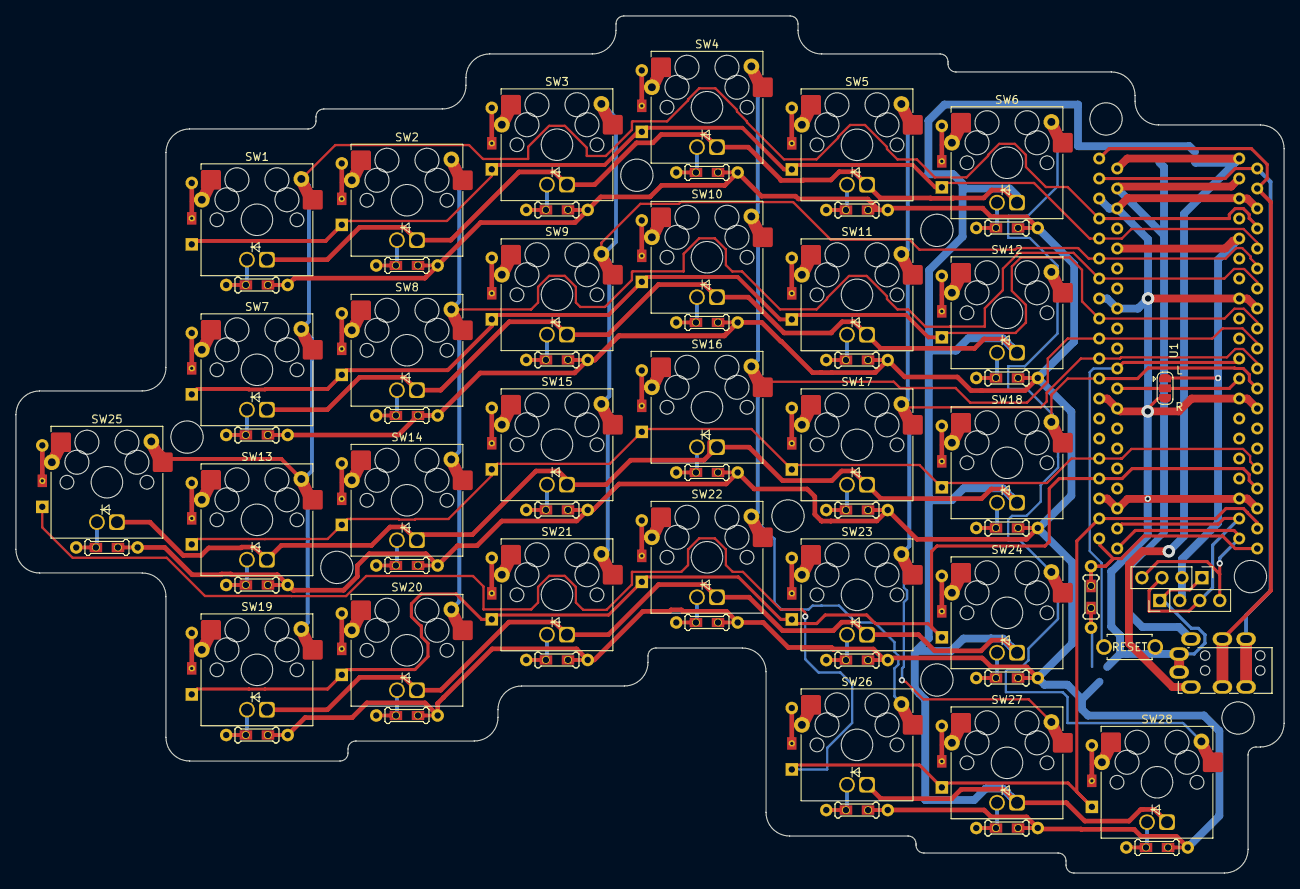
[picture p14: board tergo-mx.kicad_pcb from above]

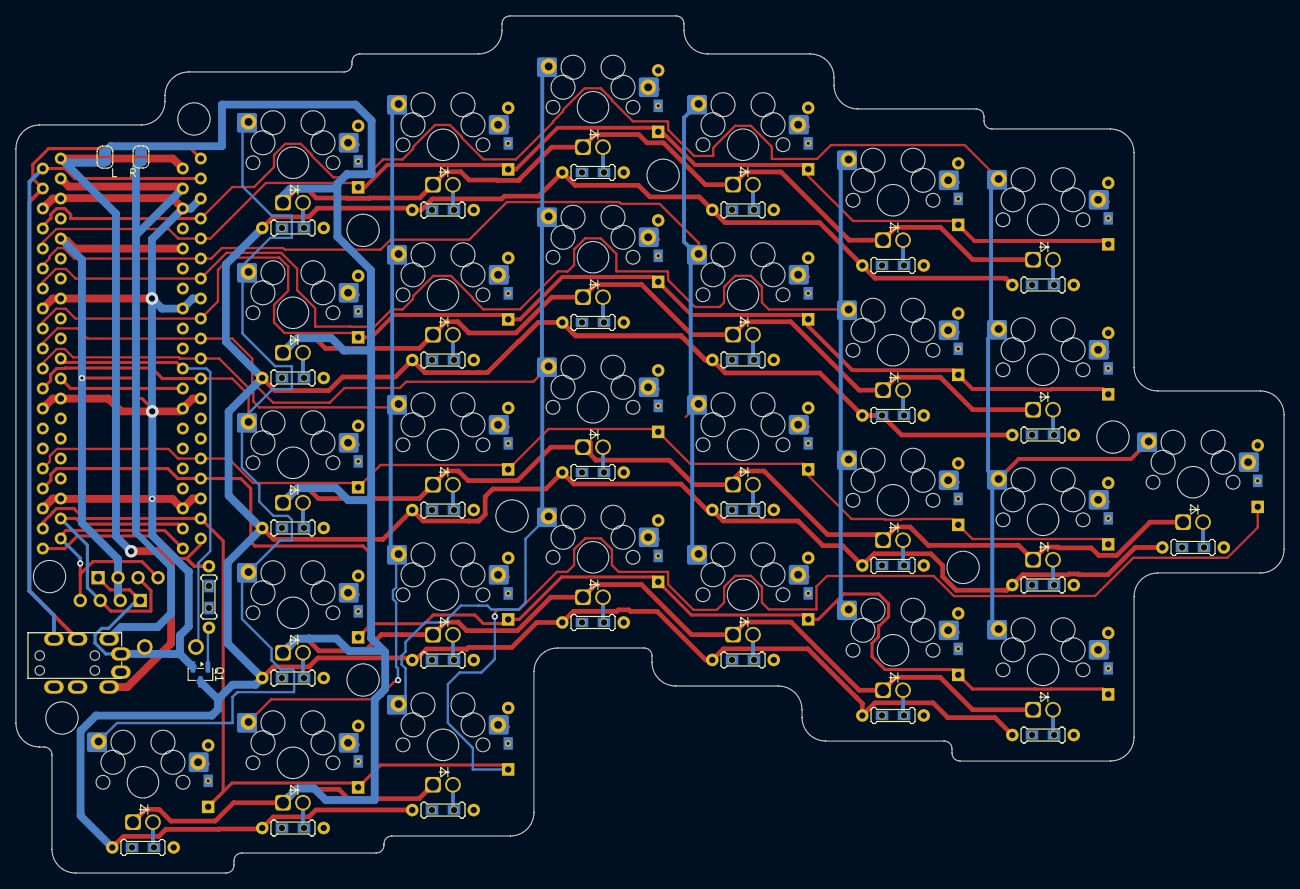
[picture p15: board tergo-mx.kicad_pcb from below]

Board: 2 copper layers, 161.0 x 108.8 mm, 131 parts (3 on the bottom side), 81 nets.

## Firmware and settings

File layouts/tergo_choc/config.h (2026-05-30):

#pragma once

// прошивка двойным нажатием на сброс https://docs.qmk.fm/platformdev_rp2040#double-tap
#define RP2040_BOOTLOADER_DOUBLE_TAP_RESET
#define RP2040_BOOTLOADER_DOUBLE_TAP_RESET_LED GP25
#define RP2040_BOOTLOADER_DOUBLE_TAP_RESET_TIMEOUT 500U

#define SERIAL_USART_FULL_DUPLEX
#define SERIAL_USART_TX_PIN GP0
#define SERIAL_USART_RX_PIN GP1

//#define SERIAL_DEBUG

// #define WS2812_PIO_USE_PIO1

/*
 * Feature disable options
 *  These options are also useful to firmware size reduction.
 */

// disable debug print:
// #undef NO_DEBUG
// #define NO_DEBUG
// force enable debug output:
#undef NO_DEBUG

// disable print:
//#define NO_PRINT
// force enable print:
#undef NO_PRINT

/* disable action features */
//#define NO_ACTION_LAYER
//#define NO_ACTION_TAPPING
//#define NO_ACTION_ONESHOT

// значения по умолчанию для oled:
// #define I2C_DRIVER I2CD1
// #define I2C1_SDA_PIN GP2
// #define I2C1_SCL_PIN GP3

#define I2C_DRIVER I2CD0
#define I2C1_SDA_PIN GP16
#define I2C1_SCL_PIN GP17

// Выкидывать в отладочную QMK console сообщения о частоте сканирования матрицы кнопок:
#define DEBUG_MATRIX_SCAN_RATE
/**
 * по состоянию этого пина прошивка определяет, работает она на левой части клавы или на правой
 * VCC - левая часть, GND - правая
 */
#define SPLIT_HAND_PIN GP22

// /** ПОДСВЕТКА */
// Для того, чтобы скомпилировалась поддержка обычной подсветки с использованием аппаратного PWM:
#define BACKLIGHT_PWM_DRIVER PWMD1
// pwm channel зависит от того, какой вывод используется для PWM
#define BACKLIGHT_PWM_CHANNEL RP2040_PWM_CHANNEL_A
// это мне посоветовал gemimi, но вроде бы нигде в кодовой базе нет такой константы:
#define SPLIT_BACKLIGHT_ENABLE

// // Указываем пин, к которому подключен затвор транзистора
#define BACKLIGHT_PIN GP18

// // Количество уровней яркости (не считая состояния "выключено")
#define BACKLIGHT_LEVELS 7

// // 0 означает, что подсветка включается при подаче логического 0 (Low) на пин.
// // 1 - для N-канальных транзисторов, 0 - для P-канальных.
#define BACKLIGHT_ON_STATE 1

// Breathing работает корявенько - виден не плавный переход между уровнями яркости. Посему отключаем
#undef BACKLIGHT_BREATHING
// #define BACKLIGHT_BREATHING 1
// #define BREATHING_PERIOD 4

// // Уровень подсветки по умолчанию (после очистки EEPROM):
#define BACKLIGHT_DEFAULT_LEVEL 1

// Опционально: настройка лимита яркости (если светодиоды греются)
// 255 = 100% мощности.
#define BACKLIGHT_LIMIT_VAL 255

// Длительность показа лого в миллисекундах
#define SHOW_LOGO_DURATION 4000
#undef QUANTUM_PAINTER_DISPLAY_TIMEOUT
#define QUANTUM_PAINTER_DISPLAY_TIMEOUT 10000

// // led pins. Их нужно здесь прописать, даже если впоследствии мы будем управлять ими вручную.
// // Видимо эти пины где-то под капотом инициализируются как выходы.
// #undef LED_NUM_LOCK_PIN
// #define LED_NUM_LOCK_PIN GP20

// #undef LED_CAPS_LOCK_PIN
// #define LED_CAPS_LOCK_PIN GP19

// #define SPLIT_LED_STATE_ENABLE

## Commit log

2026-04-09 fixed config.h. added case projects for Cherry MX and Kailh chok variants
    [config.h]
2026-04-10 reorganized folders
    [CUI_DEVICES_SJ-43504-SMT-TR.step, CUI_SJ-43614-SMT-TR.step, EC11B-SW-Horiz-15K-blue.step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]
2026-04-19 reorganize folders structure
    [CUI_DEVICES_SJ-43504-SMT-TR.step, CUI_SJ-43614-SMT-TR.step, EC11B-SW-Horiz-15K-blue.step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]
2026-05-04 choc pcb - layout
    [tergo-choc.kicad_pcb]
2026-05-10 semi-completed case for tergo-choc renamed directories
    [case-choc.FCStd, case-left.FCStd]
2026-05-26 couple of fixes in tergo-choc case
    [case-choc.FCStd]
2026-05-30 - Реализация расширения для Gnome desktop для передачи названия текущей раскладки в клавиатуру - Поменял местами PgUp/PgDn и Home/End - Задействовал светодиод Scroll Lock как индикатор не-английской 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
